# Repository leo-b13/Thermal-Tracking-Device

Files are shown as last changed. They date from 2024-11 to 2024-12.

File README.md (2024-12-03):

# Thermal Tracking Device #
* This code uses an ESP32 mini, a Panasonic Grid-EYE sensor, SG90 micro servo motors, and several electrical components in order to direct air towards a person

* Tracking Device Processing is code to be used in the Processing Application to display the data from the GridEYE
  * This requires serial data so data must be printed in the serial monitor each loop
  * Sometimes the processing code will not upload due to a NaN error. Just keep trying to upload it (maybe 3-5 times) and it should upload succesfully

* Epsilon is the main version. This was designed to work with an ESP32 mini microcontroller. The pinout is seen below.

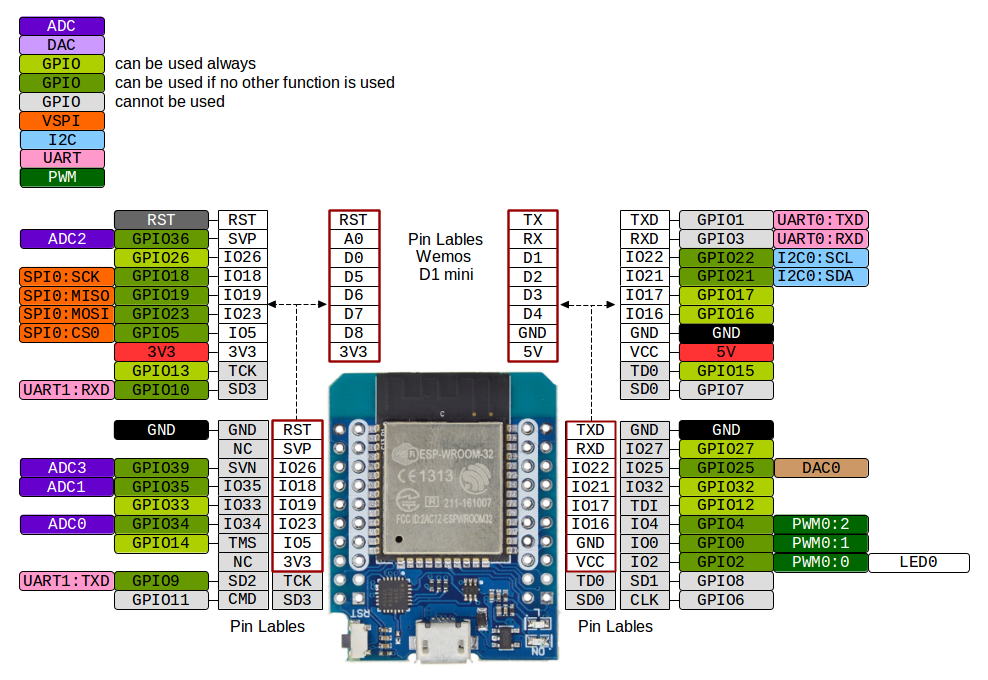
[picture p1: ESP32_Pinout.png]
ESP32 Pinout


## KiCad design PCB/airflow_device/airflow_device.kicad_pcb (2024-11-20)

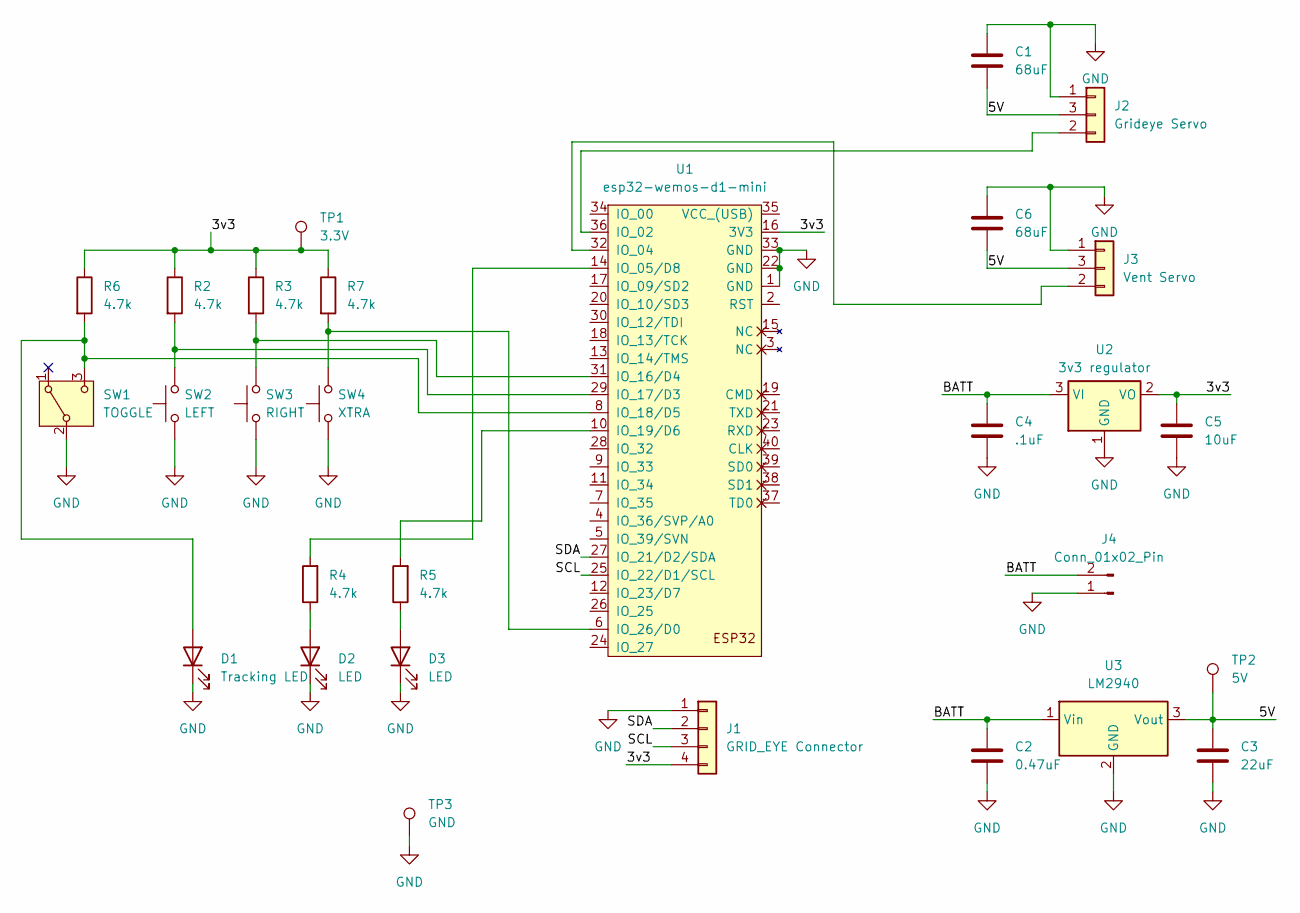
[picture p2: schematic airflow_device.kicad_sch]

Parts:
C1, C6: 68uF; CP_Radial_D7.5mm_P2.50mm
C2: 0.47uF; C_0805_2012Metric_Pad1.18x1.45mm_HandSolder
C3: 22uF; C_0805_2012Metric_Pad1.18x1.45mm_HandSolder
C4: .1uF; C_0805_2012Metric_Pad1.18x1.45mm_HandSolder
C5: 10uF; C_0805_2012Metric_Pad1.18x1.45mm_HandSolder
D1: Tracking LED; LED_D3.0mm
D2, D3: LED; LED_D3.0mm
J1: GRID_EYE Connector; PinHeader_1x04_P2.54mm_Vertical
J2: Grideye Servo; PinHeader_1x03_P2.54mm_Vertical
J3: Vent Servo; PinHeader_1x03_P2.54mm_Vertical
J4: Conn_01x02_Pin; PinSocket_1x02_P2.54mm_Vertical
R2, R3, R4, R5, R6, R7: 4.7k; R_0805_2012Metric_Pad1.20x1.40mm_HandSolder
SW1: TOGGLE; PinHeader_1x03_P2.54mm_Vertical
SW2: LEFT; SW_PUSH_6mm_H5mm
SW3: RIGHT; SW_PUSH_6mm_H5mm
SW4: XTRA; SW_PUSH_6mm_H5mm
TP1: 3.3V; TestPoint_Pad_2.5x2.5mm
TP2: 5V; TestPoint_Pad_2.5x2.5mm
TP3: GND; TestPoint_Pad_2.5x2.5mm
U1: esp32-wemos-d1-mini
U2: 3v3 regulator; TO-220-3_Vertical
U3: LM2940; TO-220-3_Vertical

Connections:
/3v3: C5.1, J1.4 (Vin), R2.1, R3.1, R6.1, R7.1, TP1.1, U1.16 (3V3), U2.2 (VO)
/5V: C1.2, C3.1, C6.2, J2.3 (Vin), J3.3 (Vin), TP2.1, U3.3 (Vout)
/BATT: C2.1, C4.1, J4.2 (BATT), U2.3 (VI), U3.1 (Vin)
/SCL: J1.3 (SCL), U1.25 (IO_22/D1/SCL)
/SDA: J1.2 (SDA), U1.27 (IO_21/D2/SDA)
GND: C1.1, C2.2, C3.2, C4.2, C5.2, C6.1, D1.1 (K), D2.1 (K), D3.1 (K), J1.1 (GND), J2.1 (GND), J3.1 (GND), J4.1 (GND), SW1.2 (B), SW2.1, SW3.1, SW4.1, TP3.1, U1.1 (GND), U1.22 (GND), U1.33 (GND), U2.1 (GND), U3.2 (GND)
unnamed: D1.2 (A), R6.2, SW1.3 (C), U1.8 (IO_18/D5)
unnamed: D2.2 (A), R4.1
unnamed: D3.2 (A), R5.1
unnamed: J2.2 (SIG), U1.36 (IO_02)
unnamed: J3.2 (SIG), U1.32 (IO_04)
unnamed: R4.2, U1.14 (IO_05/D8)
unnamed: R3.2, SW3.2, U1.31 (IO_16/D4)
unnamed: R2.2, SW2.2, U1.29 (IO_17/D3)
unnamed: R5.2, U1.10 (IO_19/D6)
unnamed: R7.2, SW4.2, U1.6 (IO_26/D0)

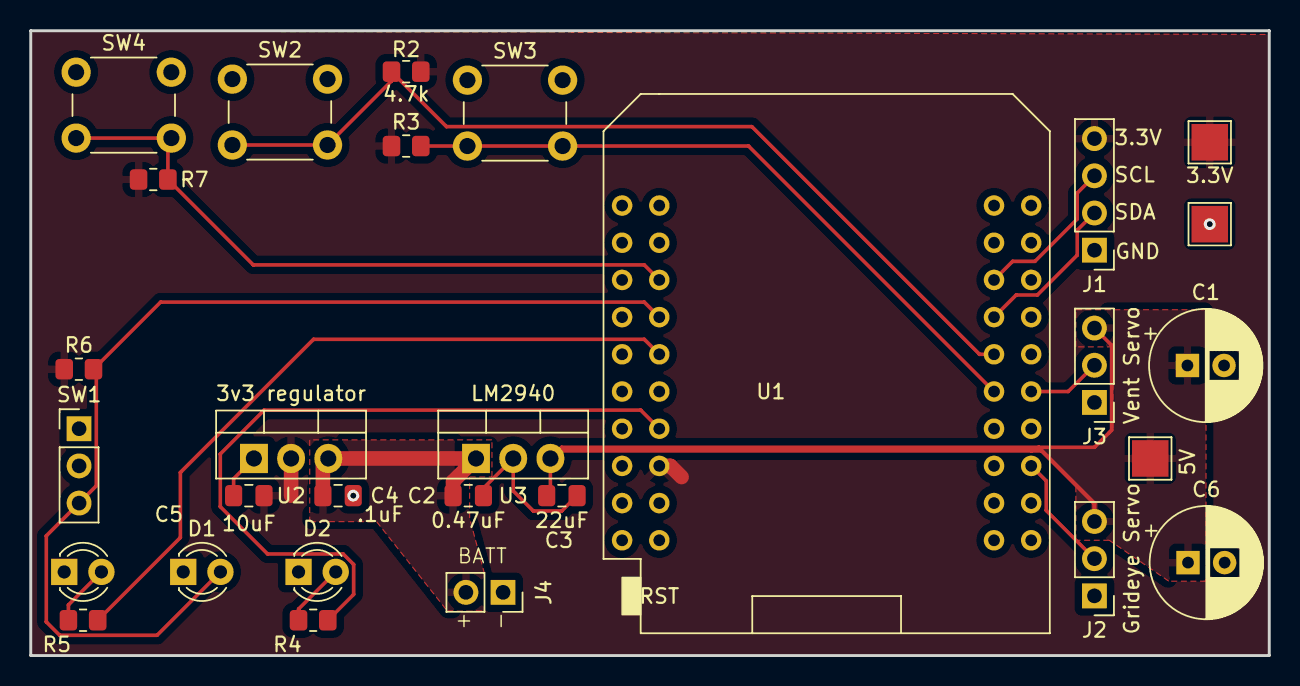
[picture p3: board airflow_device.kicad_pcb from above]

Board: 2 copper layers, 84.6 x 42.7 mm, 29 parts (0 on the bottom side), 16 nets.

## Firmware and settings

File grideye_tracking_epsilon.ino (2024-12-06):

//GridEye Tracking Code - ECSE 398 Project by Leo, Adam, and Jerry

#include <Wire.h>                              //I2C Library
#include <SparkFun_GridEYE_Arduino_Library.h>  //Grideye Library
#include <ESP32Servo.h>                        //Servo Library for ESP32


//GridEYE Parameters
GridEYE grideye;      //Initializes sensor
float tempArray[64];  //Float array to store 64 pixels (since GridEye outputs 8x8 grid). Switch to int type if you want to remove decimal points.
float minTemp = 20;   //Min temperature expected, changed by function later on

//Servo Parameters
Servo track_servo;
Servo x_servo;
int pos = 90;
int xPos = 90;
const int servoPin = 2;
const int xServoPin = 4;
int minServoAngle = 5;    // Minimum servo angle, set slightly higher than 0 to prevent excess current draw
int maxServoAngle = 180;  // Maximum servo angle


//PID Controller
double Kp, Ki, Kd;
double dt, last_time;
double integral, previous, output = 0;
double setpoint = 4.5;   //Desired center value
double deadband = 0.15;  //Deadband to prevent micro-movements with tracking servo


//Buttons / Switches
const int leftPin = 26;
const int rightPin = 17;
const int togglePin = 18;
const int sleep_pin = 16;
//#define SLEEP_PIN 0


//LED
const int led1 = 19;
const int led2 = 5;


void setup() {

  Wire.begin();  // I2C
  grideye.begin();

  Serial.begin(115200);
 

  //Servo Setup
  ESP32PWM::allocateTimer(0);
  ESP32PWM::allocateTimer(1);
  ESP32PWM::allocateTimer(2);
  ESP32PWM::allocateTimer(3);               //Allow allocation of all timers
  track_servo.setPeriodHertz(50);           // standard 50 hz servo
  track_servo.attach(servoPin, 644, 2400);  //default values almost (0-180), little more added on 0 side to prevent current draw

  x_servo.setPeriodHertz(50);
  x_servo.attach(xServoPin, 644, 2400);


  //PID Variables
  Kp = 12;
  //Ki = 0.5;
  //Kd = 0.005;
  last_time = 0;

  //Manual Control Pin Setup
  pinMode(togglePin, INPUT);
  pinMode(leftPin, INPUT);
  pinMode(rightPin, INPUT);
}


void loop() {
  bool isAutomaticMode = digitalRead(togglePin) == HIGH;

  if (isAutomaticMode) {  //If toggle switch is on -> go into automatic, otherwise go into manual control
    TrackingFunc();
  } else {
    if (digitalRead(leftPin) == LOW) {
      xPos += 1;
      xPos = constrain(xPos, minServoAngle, maxServoAngle);
      Serial.print("xPos (after left): ");
      Serial.println(xPos);
      x_servo.write(xPos);
    }
    if (digitalRead(rightPin) == LOW) {
      xPos -= 1;
      xPos = constrain(xPos, minServoAngle, maxServoAngle);
      Serial.print("xPos (after left): ");
      Serial.println(xPos);
      x_servo.write(xPos);
    }
  }
  delay(10);
}

//GridEYE Tracking Function
void TrackingFunc() {

  minTemp = minFunc();
  //Serial.print("Min temp:");
  //Serial.println(minTemp);


  float totalTemp = 0;
  float tempX = 0;
  float tempY = 0;  //Resets temperature variables, placed before loop to initialize before new data gathered

  for (int i = 0; i < 64; i++) {                    //Loop that goes through each pixel and assigns it to the temperature array
    Serial.print(grideye.getPixelTemperature(i));
    Serial.print(",");
    tempArray[i] = grideye.getPixelTemperature(i);  //Read pixel value at current i, store it in temperature array
    //tempPrintFunction(i); //To print GridEYE's temperature data, comment in/out this calling function

    int x = (i % 8) + 1;
    int y = (i / 8) + 1;  //+1 included so that the grid does not include 0 values, done for CoT calculation

    float temp = tempArray[i] - minTemp;  //Lowers value of temp array so that any slight change is more noticeable

    totalTemp += temp;  //Incrementing total temperature counter
    tempX += x * temp;  //Multiplies current temperature by its grid position for CoT calculation later on
    tempY += y * temp;
  }

  Serial.println();
  float centerX = tempX / totalTemp;
  float centerY = tempY / totalTemp;  //Gets x and y center temperature


  //Change in T calculation (for integral)
  unsigned long current_time = millis();      //Returns the number of milliseconds passed since the Arduino board began running the current program
  dt = (current_time - last_time) / 1000.00;  //Calculates change in time in seconds
  last_time = current_time;                   //Sets previous time for next iteration


  //Error + Servo Writing
  double error = centerX - setpoint;                   //Calculates error (distance between current centerX temp and setpoint, which is usually 4.5 (middle))
  output = pid(error);                                 //Goes to PID function to calculate error output
  pos += output;                                       
  pos = constrain(pos, minServoAngle, maxServoAngle);  //Constrains position variable between 0 and 180 to prevent stress on motor
  int pos_adj = 16;
  float pos_adj_2 = (pos-90) / 6;
  xPos = (180 - pos) + pos_adj + pos_adj_2;
  track_servo.write(pos); 
  x_servo.write(xPos);
  //debugFunction(centerX, error, output, pos, dt, current_time);  //Debug function, comment out/in
}


//PID Error Function
double pid(double error) {
  double proportional = error;

  if (abs(error) > deadband) {  //Reduction things for when within deadband (close to error) to prevent excess jittering
    //proportional *= 0.5;
    integral += error * dt;
    integral = constrain(integral, -20, 20);
  } else {
    integral = 0;
  }

  //Integral wind-up preventation when at max/min servo angles
  if (pos >= maxServoAngle || output <= minServoAngle) {
    integral = 0;
  }

  double derivative = (error - previous) / dt;
  previous = error;
  derivative = constrain(derivative, -20, 20);

  integral = 0;
  derivative = 0;
  double output = (Kp * proportional) + (Ki * integral) + (Kd * derivative);

  //pidPrintFunction(proportional, integral, derivative);

  return output;
}


//Mintemp setup
float minFunc() {
  float minTemp = 20;
  for (int i = 0; i < 64; i++) {  //Loop that goes through each pixel and assigns it to the temperature array
    tempArray[i] = grideye.getPixelTemperature(i);
    if (tempArray[i] < minTemp) {
      minTemp = tempArray[i];  // Update minTemp with the new lowest temperature
    }
  }
  minTemp = constrain(minTemp, 15, 20);  //Constraints set up incase of glitches / unwanted temperature readings

  return minTemp;
}


//Print GridEYE Data Function
void tempPrintFunction(int i) {
  Serial.print(tempArray[i]);  //Prints data from temperature array
  Serial.print(" ");           //Prints blank space between values to make them easier to read

  if ((i + 1) % 8 == 0) {  //If the ith iteration + 1 is divisible by 8, run code in the loop
    Serial.println();      //Start a new line (Since i goes up to 64, makes 8x8 grid of data in monitor)
  }

  if ((i + 1) == 64) {
    Serial.println();  //Prints empty lines in serial monitor to make each dataset visually distinct
    Serial.println();
  }
}


//PID Error Debug Function
void pidPrintFunction(double proportional, double integral, double derivative) {
  Serial.println("------ PID Components ------");
  Serial.print("Proportional: ");
  Serial.println(proportional);
  Serial.print("Integral: ");
  Serial.println(integral);
  Serial.print("Derivative: ");
  Serial.println(derivative);
  Serial.println("---------------------------\n");
}


//General Debug Info Function
void debugFunction(float centerX, double error, double output, int pos, long dt, unsigned long current_time) {
  Serial.println("------ Debug Info ------");
  Serial.print("Center X: ");
  Serial.println(centerX);
  Serial.print("Error: ");
  Serial.println(error);
  Serial.print("Output: ");
  Serial.println(output);
  Serial.print("Pos: ");
  Serial.println(pos);
  Serial.print("DT: ");
  Serial.println(dt);
  Serial.println("------------------------\n");
}

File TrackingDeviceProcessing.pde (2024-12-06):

import processing.serial.*;

String myString = null;
Serial myPort;  // The serial port

float[] temps =  {0,0,0,0,0,0,0,0,0,0,0,0,0,0,0,0,0,0,0,0,0,0,0,0,0,0,0,0,0,0,0,0,0,0,0,0,0,0,0,0,0,0,0,0,0,0,0,0,0,0,0,0,0,0,0,0,0,0,0,0,0,0,0,0};

// The statements in the setup() function 
// execute once when the program begins
void setup() {
  size(400, 400);  // Size must be the first statement
  noStroke();
  frameRate(30);
  
  // Print a list of connected serial devices in the console
  printArray(Serial.list());
  // Depending on where your GridEYE falls on this list, you
  // may need to change Serial.list()[0] to a different number
  myPort = new Serial(this, Serial.list()[0], 115200);
  myPort.clear();
  // Throw out the first chunk in case we caught it in the 
  // middle of a frame
  myString = myPort.readStringUntil(13);
  myString = null;
  // change to HSB color mode, this will make it easier to color
  // code the temperature data
  colorMode(HSB, 360, 100, 100);
}

// The statements in draw() are executed until the 
// program is stopped. Each statement is executed in 
// sequence and after the last line is read, the first 
// line is executed again.
void draw() { 
  // When there is a sizeable amount of data on the serial port
  // read everything up to the first linefeed
  if (myPort.available() > 64) {
    myString = myPort.readStringUntil(13);

    // readStringUntil is a non-blocking function and will return null if it can't find the linefeed
    if (myString == null) {
      return;
    }
    
    // generate an array of strings that contains each of the comma-separated values
    String splitString[] = splitTokens(myString, ",");
    
    // for each of the 64 values, map the temperatures between 20C and 35C
    // to the blue through red portion of the color space
    for (int q = 0; q < 64; q++) {
      temps[q] = map(float(splitString[q]), 20, 35, 240, 360);
    }
  }

  // Prepare variables needed to draw our heatmap
  int x = 0;
  int y = 0;
  int i = 0;
  background(0); // Clear the screen with a black background

  // each Grid-EYE pixel will be represented by a 50px square:
  // because 50 x 8 = 400, we draw squares until our y location
  // is 400
  while (y < 400) {
    // Flip the row index: subtract the current row index from 7 (0-based)
    int flippedRow = 7 - (y / 50);

    // for each increment in the y direction, draw 8 boxes in the
    // x direction, creating a 64 pixel matrix
    while (x < 400) {
      // Calculate the index in the temps array, considering the flipped row
      i = flippedRow * 8 + (x / 50);

      // Set the color for the current temperature
      fill(temps[i], 100, 100);
      rect(x, y, 50, 50);
      x = x + 50;
    }

    y = y + 50;
    x = 0;
  }

  // Add a Gaussian blur to the canvas in order to create a rough
  // visual interpolation between pixels.
  //filter(BLUR, 10);
}

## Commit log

2024-11-09 Epsilon: Delta tracking + integration
    Integration includes button and servo testing
2024-11-09 Added servo pos stuff
2024-11-13 Initial Commit for PCB
    Included are footprints and symbols for the components that I had to make custom.
    [airflow_device.kicad_pcb, airflow_device.kicad_sch]
2024-11-13 Adding more components
    [airflow_device.kicad_sch]
2024-11-13 WIP Searching, General Adjustment
    -added wip searching function
    -messed with some functions, got rid of some and modified some
    -got rid of Y vent / motor stuff since we won't be using it
    -moved some stuff around in general
    [grideye_tracking_epsilon.ino]
2024-11-14 Adding more components, and fixing footprints
    [airflow_device.kicad_pcb, airflow_device.kicad_sch]
2024-11-14 Fixed pin assignment, for testing
    [grideye_tracking_epsilon.ino]
2024-11-16 Adding more footprints
    [airflow_device.kicad_sch]
2024-11-18 Likely Functional PCB
    [airflow_device.kicad_pcb, airflow_device.kicad_sch]
2024-11-19 Added 68uF caps for servos
    [airflow_device.kicad_pcb, airflow_device.kicad_sch]
2024-11-20 Fixed servo current draw
    -Fixed servo current draw (changed PWM settings)
    [grideye_tracking_epsilon.ino]
2024-11-20 PCB Done
    [airflow_device-B_Cu.gbr, airflow_device-B_Mask.gbr, airflow_device-B_Paste.gbr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]
2024-11-27 WIP PID testing added
2024-12-02 Updated for PCB + Processing
2024-12-06 Added vent servo motor + upped proportional a bit
